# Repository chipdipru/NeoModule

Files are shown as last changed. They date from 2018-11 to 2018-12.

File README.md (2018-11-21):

# NeoModule
video1
Alt text for your video (https://youtu.be/5BwNlenJXx8)

video2
Alt text for your video (https://youtu.be/3Q9jxst66bE)

video3
Alt text for your video (https://youtu.be/zdmGbAN1B0c)

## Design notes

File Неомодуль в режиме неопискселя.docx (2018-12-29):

Неомодуль в режиме неопискселя
Когда данных нет, линия данных находится в нуле.
Когда на линии появляется передний фронт, значит данные пошли, начинается обработка сигнала.
Модуль обрабатывает входной сигнал (измеряет длительность импульса) и сохраняет полученные значения в буфере.
Окончание данных - нахождение линии данных в нуле более 50 мкс (или 80 мкс, зависит от светодиодов).
У нас выбрано максимально возможное время нуля на линии, универсальное, чтобы со всеми светодиодами работало.
При обнаружении заднего фронта на линии данных начинается измерение времени.
Если передний фронт не появляется, а время линии данных в состоянии нуля равно времени окончания данных,
обработка входного сигнала прекращается. Первые 3 или 4 байта данных (зависит от светодиода) модуль оставляет себе, это его данные. На основании оставшихся данных формируется выходная ШИМ-последовательность для следующих светодиодов.
После передачи данных следующим светодиодам, модуль зажигает свой светодиод.
После этого модуль ждет появление переднего фронта на входе и т.д.

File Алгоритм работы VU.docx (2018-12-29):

Алгоритм работы VU-метра
По каждому каналу делается выборка в 128 значений. Из них выбирается максимальное.
Это значение сравнивается с таблицей значений АЦП, соответствующих громкости звука в дБ.
Находится количество светодиодов, которые должны светиться, чтобы отобразить нужный уровень громкости.
Зажигание (если новое значение больше текущего) или гашение (если новое значение меньше текущего)
происходит по одному светодиоду за раз, что создает движение шкалы;
т.е. не просто зажигается новое количество светодиодов,
а выполняется переход по одному светодиоду от текущего положения шкалы к новому положению.
Когда шкала принимает новое конечное положение и в левом, и в правом каналах, измерения сигналов повторяются и т.д.
При движении вверх шкала подбрасывает красный светодиод.
Когда шкала начинает опускаться, красный светодиод зависает вверху на определенное количество циклов обновления шкалы,
затем начинает опускаться в определенное количество раз медленнее основной шкалы.
Когда основная шкала сталкивается с красным светодиодом, он опять подбрасывается вверх и т.д.

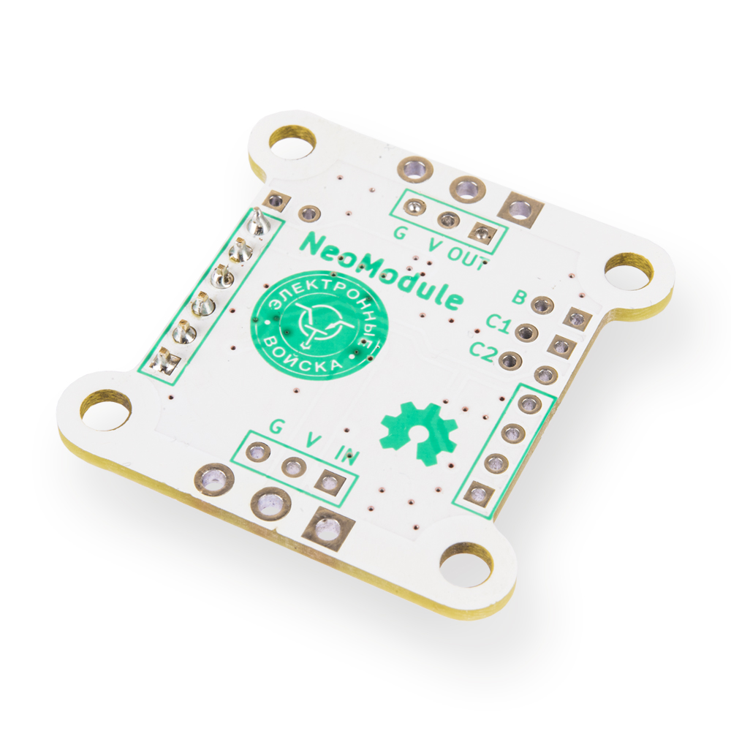
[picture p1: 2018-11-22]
NeoModule_2.jpg

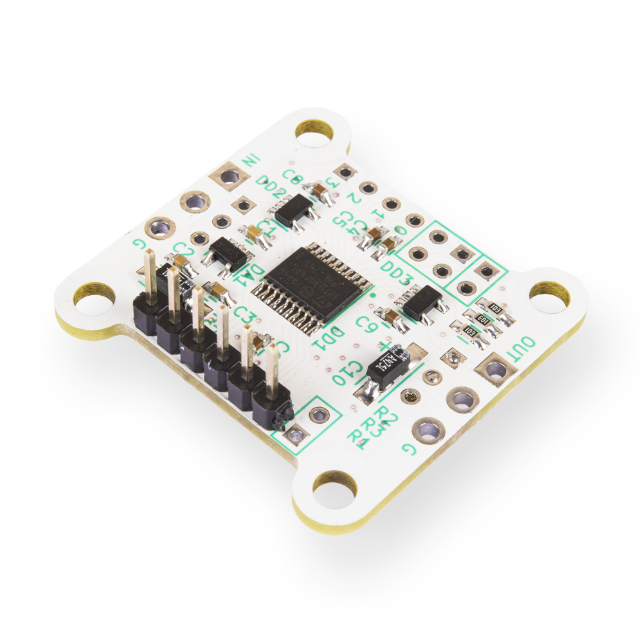
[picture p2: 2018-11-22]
NeoModule_1.jpg

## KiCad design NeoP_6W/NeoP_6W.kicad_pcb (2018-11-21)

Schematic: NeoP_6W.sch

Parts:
C1: 4,7uF; CP_EIA-3216-18_Kemet-A_Pad1.58x1.35mm_HandSolder
D1: LED_RGB; LED_RGB_Getian_GT-P6PRGB4303
J1: Conn_01x06_Male; Pin_Header_Straight_1x06
J2, J3: Conn_01x03_Female; Socket_Strip_Straight_1x03
Q1, Q2, Q3: IRLML2060TRPBF; SOT-23
Q4, Q5, Q6: MMBT2222A; SOT-23
R1, R2, R3: 47k; R_0603_1608Metric_Pad1.05x0.95mm_HandSolder
R4, R5, R6: 1,8R; R_1206_HandSoldering
R7: 4,7k; R_0603_1608Metric_Pad1.05x0.95mm_HandSolder
TH1: Thermistor_NTC; R_0603_1608Metric_Pad1.05x0.95mm_HandSolder

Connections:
+5V: D1.4, D1.5, D1.6, J1.6, J2.2, J3.2, R7.2
B: J1.2, R3.2
G: J1.3, R2.2
GND: C1.2, J1.5, J2.3, J3.3, Q4.2 (C), Q5.2 (C), Q6.2 (C), R4.1, R5.1, R6.1, TH1.2
unnamed: D1.1, Q3.3 (D)
unnamed: D1.2, Q2.3 (D)
unnamed: D1.3, Q1.3 (D)
unnamed: Q1.1 (G), Q4.3 (E), R1.1
unnamed: Q1.2 (S), Q4.1 (B), R4.2
unnamed: Q2.1 (G), Q5.3 (E), R2.1
unnamed: Q2.2 (S), Q5.1 (B), R5.2
unnamed: Q3.1 (G), Q6.3 (E), R3.1
unnamed: Q3.2 (S), Q6.1 (B), R6.2
R: J1.4, R1.2
TC: C1.1, J1.1, R7.1, TH1.1

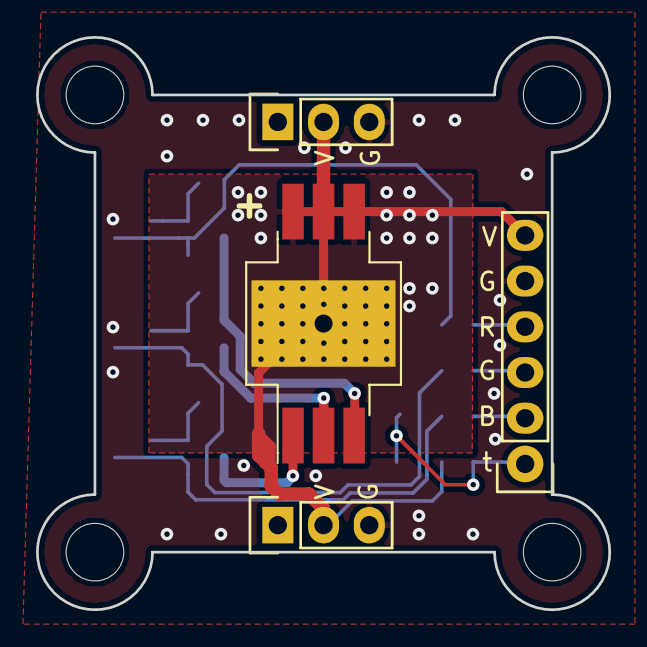
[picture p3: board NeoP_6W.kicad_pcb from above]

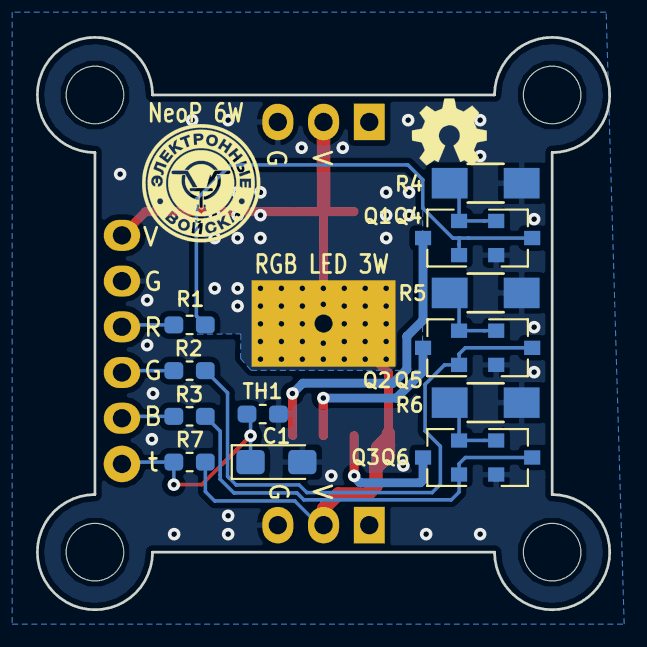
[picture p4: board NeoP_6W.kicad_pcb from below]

Board: 2 copper layers, 31.8 x 31.8 mm, 19 parts (15 on the bottom side), 15 nets.

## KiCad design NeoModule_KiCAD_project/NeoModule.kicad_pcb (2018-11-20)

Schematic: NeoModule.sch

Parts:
C1, C3: 2,2мкФ; C_0603_HandSoldering
C2: 0,01мкФ; C_0603_HandSoldering
C4, C5, C6, C8, C9: 0,1мкФ; C_0603_HandSoldering
C7, C10: 10мкФ; TantalC_SizeA_EIA-3216_HandSoldering_mm
DA1: LP2985-3.3; SOT-23-5_mm
DD1: STM32F030F4Px; TSSOP-20_4.4x6.5mm_Pitch0.65mm
DD2: MC74VHC1GT125; SOT-23-5_mm
DD3: 74AHC1G125; SOT-23-5_mm
R1, R2, R3: 10k; R_0603_HandSoldering
XP1: Conn_02x02_Odd_Even; Pin_Header_Straight_2x02_mm
XP2, XP5: Conn_01x02; Pin_Header_Straight_1x02_mm
XP3: Conn_01x04; Pin_Header_Straight_1x04_mm
XP4: Conn_01x06; Pin_Header_Straight_1x06_mm
XP6, XP7: Conn_01x03; Pin_Header_Straight_1x03_mm

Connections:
3V3: C3.1, C5.2, C6.2, C7.1, C8.2, DA1.5 (VOUT), DD1.5, DD1.16, DD2.5 (VCC), XP1.1, XP1.3, XP2.1
DIN: DD2.2, XP6.1
DOUT: DD3.4, XP7.1
GND: C1.2, C2.2, C3.2, C4.2, C5.1, C6.1, C7.2, C8.1, C9.1, C10.2, DA1.2 (GND), DD1.15, DD2.1, DD2.3 (GND), DD3.1, DD3.3 (GND), R1.2, R2.1, R3.1, XP4.5, XP6.3, XP7.3
LED_IN: DD1.12, DD2.4
LED_OUT: DD1.13, DD3.2
unnamed: C2.1, DA1.4 (BP)
unnamed: C4.1, DD1.4
unnamed: DD1.1, R1.1, XP2.2
unnamed: DD1.2, R3.2, XP1.2
unnamed: DD1.3, R2.2, XP1.4
OUT1: DD1.6, XP3.4
OUT2: DD1.7, XP3.3
OUT3: DD1.8, XP3.2
OUT4: DD1.9, XP3.1
OUT5: DD1.11, XP4.1
OUT6: DD1.10, XP4.2
OUT7_TX: DD1.17, XP4.3
OUT8_RX: DD1.18, XP4.4
SWDCLK: DD1.20, XP5.2
SWDIO: DD1.19, XP5.1
VIN: C1.1, C9.2, C10.1, DA1.1 (VIN), DA1.3 (ON/~OFF~), DD3.5 (VCC), XP4.6, XP6.2, XP7.2

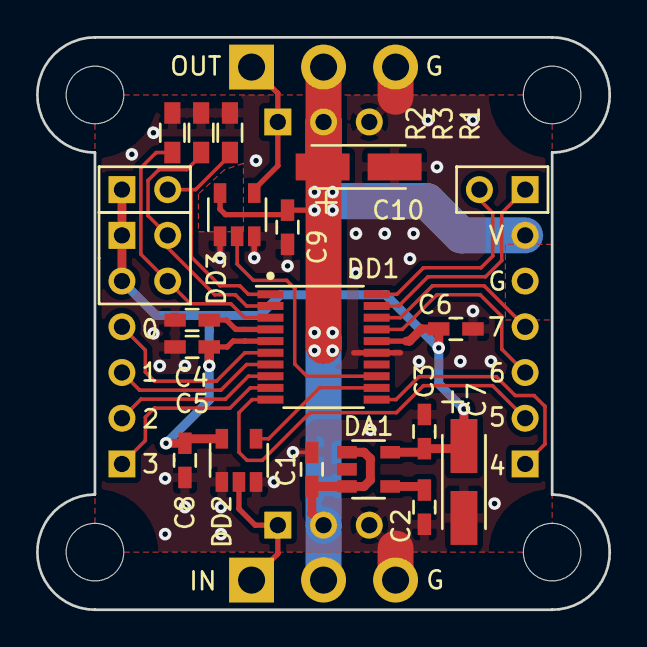
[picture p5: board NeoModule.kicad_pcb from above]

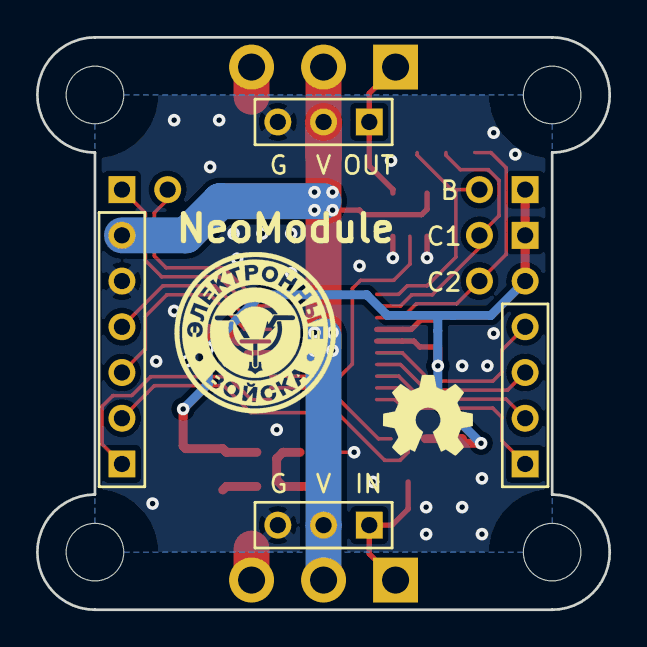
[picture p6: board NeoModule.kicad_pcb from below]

Board: 2 copper layers, 31.8 x 31.8 mm, 24 parts (4 on the bottom side), 22 nets.

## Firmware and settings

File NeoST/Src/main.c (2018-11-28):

/*
********************************************************************************
* COPYRIGHT(c) ЗАО «ЧИП и ДИП», 2018
* 
* Программное обеспечение предоставляется на условиях «как есть» (as is).
* При распространении указание автора обязательно.
********************************************************************************
*/


#include "NeoSTM_board.h"
#include "NeoLED.h"


volatile uint8_t State = 0;
static void (*DataProcessing)(uint8_t*);

int main()
{
  Module_Init();
  
  for(;;)
  {
    __WFI();
    
    if (State == DATA_AVAILABLE)
    {
      State = 0;
      
      uint8_t Data[DATA_BYTES_MAX];
      NeoGetData(Data);
      DataProcessing(Data);      
      NeoResume();
    }
  }
}
//------------------------------------------------------------------------------
void Module_Init()
{
  //HSI, PLL, 48 MHz
  FLASH->ACR = FLASH_ACR_PRFTBE | (uint32_t)FLASH_ACR_LATENCY;  
  RCC->CFGR |= (uint32_t)(RCC_CFGR_PLLSRC_HSI_DIV2 | RCC_CFGR_PLLMUL12);
  RCC->CR |= RCC_CR_PLLON;
  while((RCC->CR & RCC_CR_PLLRDY) == 0);
  RCC->CFGR &= (uint32_t)((uint32_t)~(RCC_CFGR_SW));
  RCC->CFGR |= (uint32_t)RCC_CFGR_SW_PLL;
  while ((RCC->CFGR & (uint32_t)RCC_CFGR_SWS) != (uint32_t)RCC_CFGR_SWS_PLL);
  
  RCC->AHBENR |= RCC_AHBENR_GPIOAEN | RCC_AHBENR_GPIOFEN;
  
  uint8_t Config = CONFIG_GPIO->IDR & ((1 << DATA_SIZE_PIN) || (1 << FUNCTION_PIN));
  
  RCC->AHBENR &= ~RCC_AHBENR_GPIOFEN;
  
  NeoInit(((Config & (1 << DATA_SIZE_PIN)) >> DATA_SIZE_PIN), &LEDReset);
  
  if (((Config & (1 << FUNCTION_PIN)) >> FUNCTION_PIN) == FUNCTION_PWM)
  {
    DataProcessing = SetPWMs;
    
    PWM_GPIO->AFR[1] |= (PWM_2_TIM_AF << (4 * (PWM_2_PIN - 8))) | (PWM_3_TIM_AF << (4 * (PWM_3_PIN - 8)));
    PWM_GPIO->AFR[0] |= (PWM_1_TIM_AF << (4 * PWM_1_PIN));
    PWM_GPIO->MODER |= ((2 << (2 * PWM_1_PIN)) | (2 << (2 * PWM_2_PIN)) | (2 << (2 * PWM_3_PIN)));
    RCC->APB2ENR |= PWM_2_CLK_EN;
    RCC->APB1ENR |= PWM_1_CLK_EN;
  
    PWM_1_TIMER->PSC = PWM_PSC;
    PWM_1_TIMER->ARR = PWM_ARR;
    PWM_1_TIMER->CCR1 = 0;
    PWM_1_TIMER->CCMR1 = TIM_CCMR1_OC1M_2 | TIM_CCMR1_OC1M_1 | TIM_CCMR1_OC1PE;
    PWM_1_TIMER->CCER = TIM_CCER_CC1E;
  
    PWM_2_TIMER->PSC = PWM_PSC;
    PWM_2_TIMER->ARR = PWM_ARR;
    PWM_2_TIMER->CCR2 = 0;
    PWM_2_TIMER->CCR3 = 0;
    PWM_2_TIMER->CCMR1 = TIM_CCMR1_OC2M_2 | TIM_CCMR1_OC2M_1 | TIM_CCMR1_OC2PE;
    PWM_2_TIMER->CCMR2 = TIM_CCMR2_OC3M_2 | TIM_CCMR2_OC3M_1 | TIM_CCMR2_OC3PE;
    PWM_2_TIMER->BDTR = TIM_BDTR_MOE;
    PWM_2_TIMER->CCER = TIM_CCER_CC2E | TIM_CCER_CC3E;
  
    PWM_1_TIMER->EGR = TIM_EGR_UG;
    PWM_2_TIMER->EGR = TIM_EGR_UG;
    PWM_1_TIMER->CR1 |= TIM_CR1_CEN | TIM_CR1_ARPE;
    PWM_2_TIMER->CR1 |= TIM_CR1_CEN | TIM_CR1_ARPE;
  }
  
  else
  {
    DataProcessing = SetOUTs;
    
    OUT_GPIO->MODER |= (1 << (2 * OUT_PIN_0)) | (1 << (2 * OUT_PIN_1)) | (1 << (2 * OUT_PIN_2)) | (1 << (2 * OUT_PIN_3)) | \
                       (1 << (2 * OUT_PIN_4)) | (1 << (2 * OUT_PIN_5)) | (1 << (2 * OUT_PIN_6)) | (1 << (2 * OUT_PIN_7));
  }
  
  NeoStart();
}
//------------------------------------------------------------------------------
void LEDReset()
{
  State = DATA_AVAILABLE;
}
//------------------------------------------------------------------------------
void SetPWMs(uint8_t *Data)
{
  PWM_1_TIMER->CCR1 = Data[2];
  PWM_2_TIMER->CCR2 = Data[0];
  PWM_3_TIMER->CCR3 = Data[1];
}
//------------------------------------------------------------------------------
void SetOUTs(uint8_t *Data)
{
  for (uint8_t i = 0; i < OUTPUTS_COUNT; i++)
  {
    if ((Data[0] & (1 << i)) == (1 << i))
      OUT_GPIO->ODR |= OUTPUTS[i];
    else
      OUT_GPIO->ODR &= ~OUTPUTS[i];
  }
}

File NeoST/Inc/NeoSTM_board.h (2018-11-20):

/*
********************************************************************************
* COPYRIGHT(c) ЗАО «ЧИП и ДИП», 2018
* 
* Программное обеспечение предоставляется на условиях «как есть» (as is).
* При распространении указание автора обязательно.
********************************************************************************
*/




#ifndef __NEO_STM_BOARD_H
#define __NEO_STM_BOARD_H

#include "stm32f030x6.h"



#define       DATA_SIZE_PIN                0
#define       FUNCTION_PIN                 1
#define       CONFIG_GPIO                  GPIOF

#define       DIN_PIN                      6
#define       DIN_GPIO                     GPIOA

#define       DOUT_PIN                     7
#define       DOUT_GPIO                    GPIOA

#define       NC_PIN                       1
#define       NC_GPIO                      GPIOB

//выходы
#define       OUT_GPIO                     GPIOA
#define       OUT_PIN_0                    0
#define       OUT_PIN_1                    1
#define       OUT_PIN_2                    2
#define       OUT_PIN_3                    3
#define       OUT_PIN_4                    5
#define       OUT_PIN_5                    4
#define       OUT_PIN_6                    9
#define       OUT_PIN_7                    10

#define       OUTPUTS_COUNT                8

//таймеры для ШИМ
#define       PWM_GPIO                     GPIOA
#define       PWM_1_PIN                    4
#define       PWM_2_PIN                    9
#define       PWM_3_PIN                    10
#define       PWM_1_TIM_AF                 4
#define       PWM_2_TIM_AF                 2
#define       PWM_3_TIM_AF                 2
#define       PWM_1_TIMER                  TIM14
#define       PWM_2_TIMER                  TIM1
#define       PWM_3_TIMER                  TIM1
#define       PWM_1_CLK_EN                 RCC_APB1ENR_TIM14EN
#define       PWM_2_CLK_EN                 RCC_APB2ENR_TIM1EN
#define       PWM_3_CLK_EN                 RCC_APB2ENR_TIM1EN


#define       MAX_BRIGHTNESS               255
#define       PWM_PSC                      187
#define       PWM_ARR                      (MAX_BRIGHTNESS - 1)

#define       DATA_AVAILABLE               1

#define       FUNCTION_PWM                 0
#define       FUNCTION_OUTPUT              1


extern const uint16_t OUTPUTS[OUTPUTS_COUNT];


void Module_Init();

void LEDReset();

void SetPWMs(uint8_t *Data);

void SetOUTs(uint8_t *Data);


#endif //__NEO_STM_BOARD_H

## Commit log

2018-11-20 KiCad project PCB
    [NeoModule-B.Cu.gbr, NeoModule-B.Mask.gbr, NeoModule-B.SilkS.gbr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]
2018-11-20 firmware for STM32F030F4P6
2018-11-21 Board for three LEDs. 3x1W. KiCad project
    [NeoP_1x3-B.Cu.gbr, NeoP_1x3-B.Mask.gbr, NeoP_1x3-B.Paste.gbr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]
2018-11-21 Board for RGB LED. 1x3W. KiCad project
    [NeoP_6W-B.Cu.gbr, NeoP_6W-B.Mask.gbr, NeoP_6W-B.Paste.gbr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]

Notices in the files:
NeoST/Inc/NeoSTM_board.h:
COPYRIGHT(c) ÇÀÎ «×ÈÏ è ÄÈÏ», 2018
